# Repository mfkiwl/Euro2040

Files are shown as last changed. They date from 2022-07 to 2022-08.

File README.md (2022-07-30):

# Euro2040
 
### An RP2040 based development board designed for use in Eurorack modules

The key aims of this project are to create a board which can be used to create a Eurorack module (or standalone synthesiser) with no need for extra buffering or active circuitry.  
The board will contain internal buffering, amplification, and protection, to allow the GPIO pins to be used with up to 12V signals, allowing users to connect the pins directly to jacks to interface with other Eurorack compliant modules.

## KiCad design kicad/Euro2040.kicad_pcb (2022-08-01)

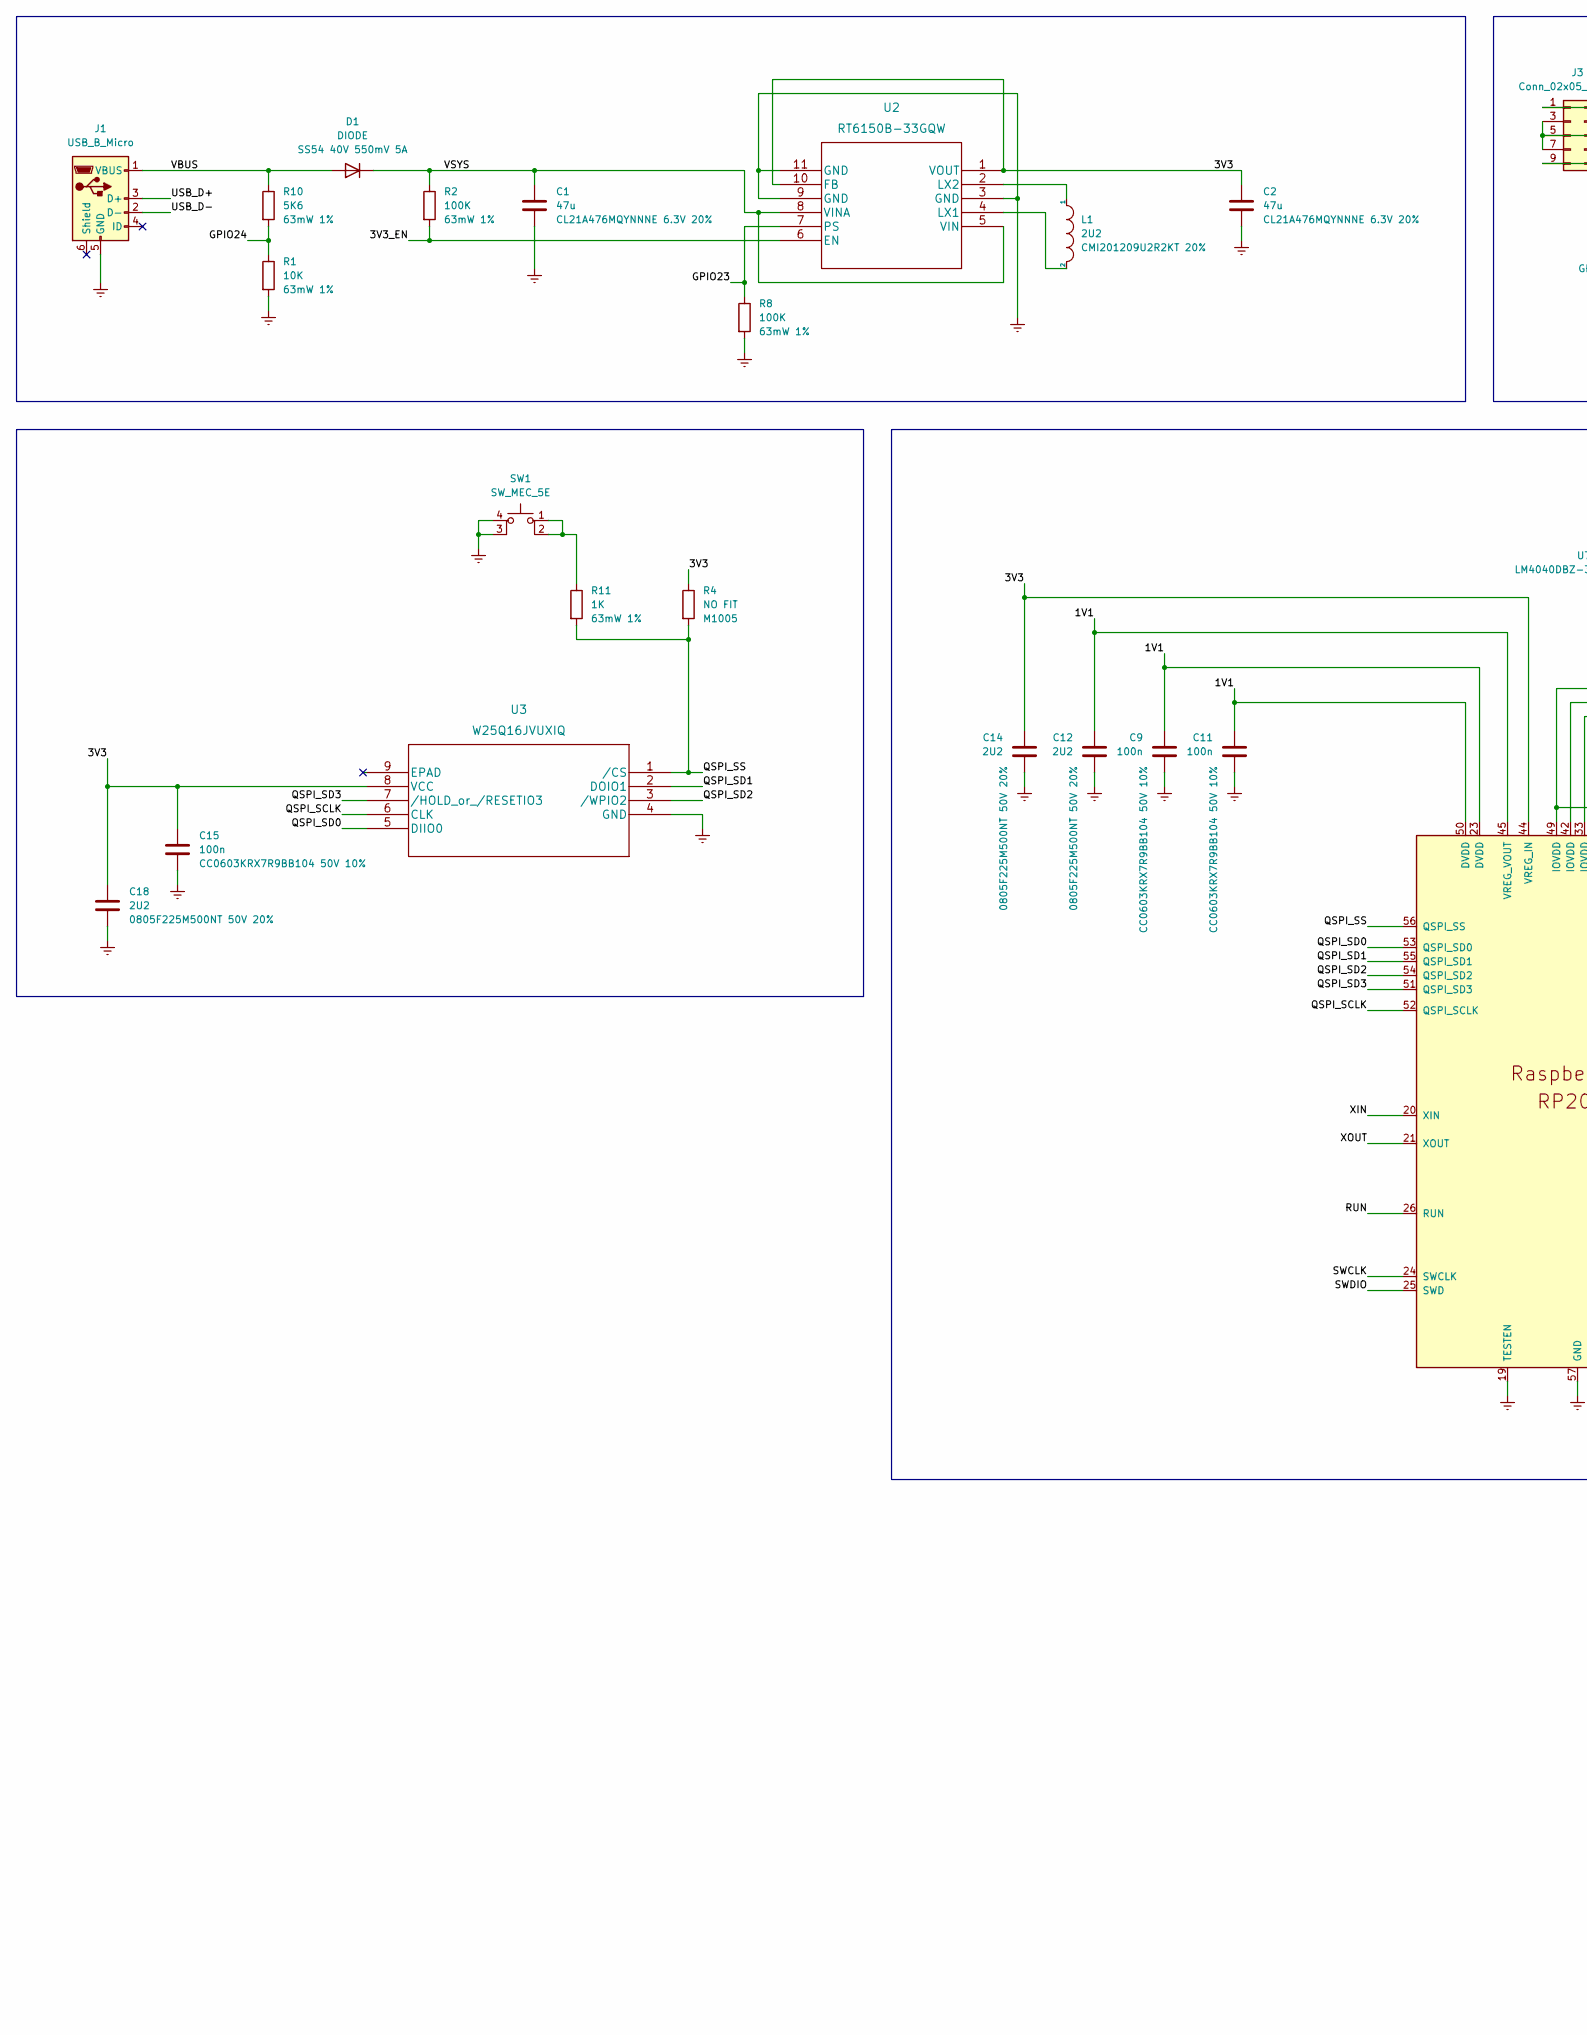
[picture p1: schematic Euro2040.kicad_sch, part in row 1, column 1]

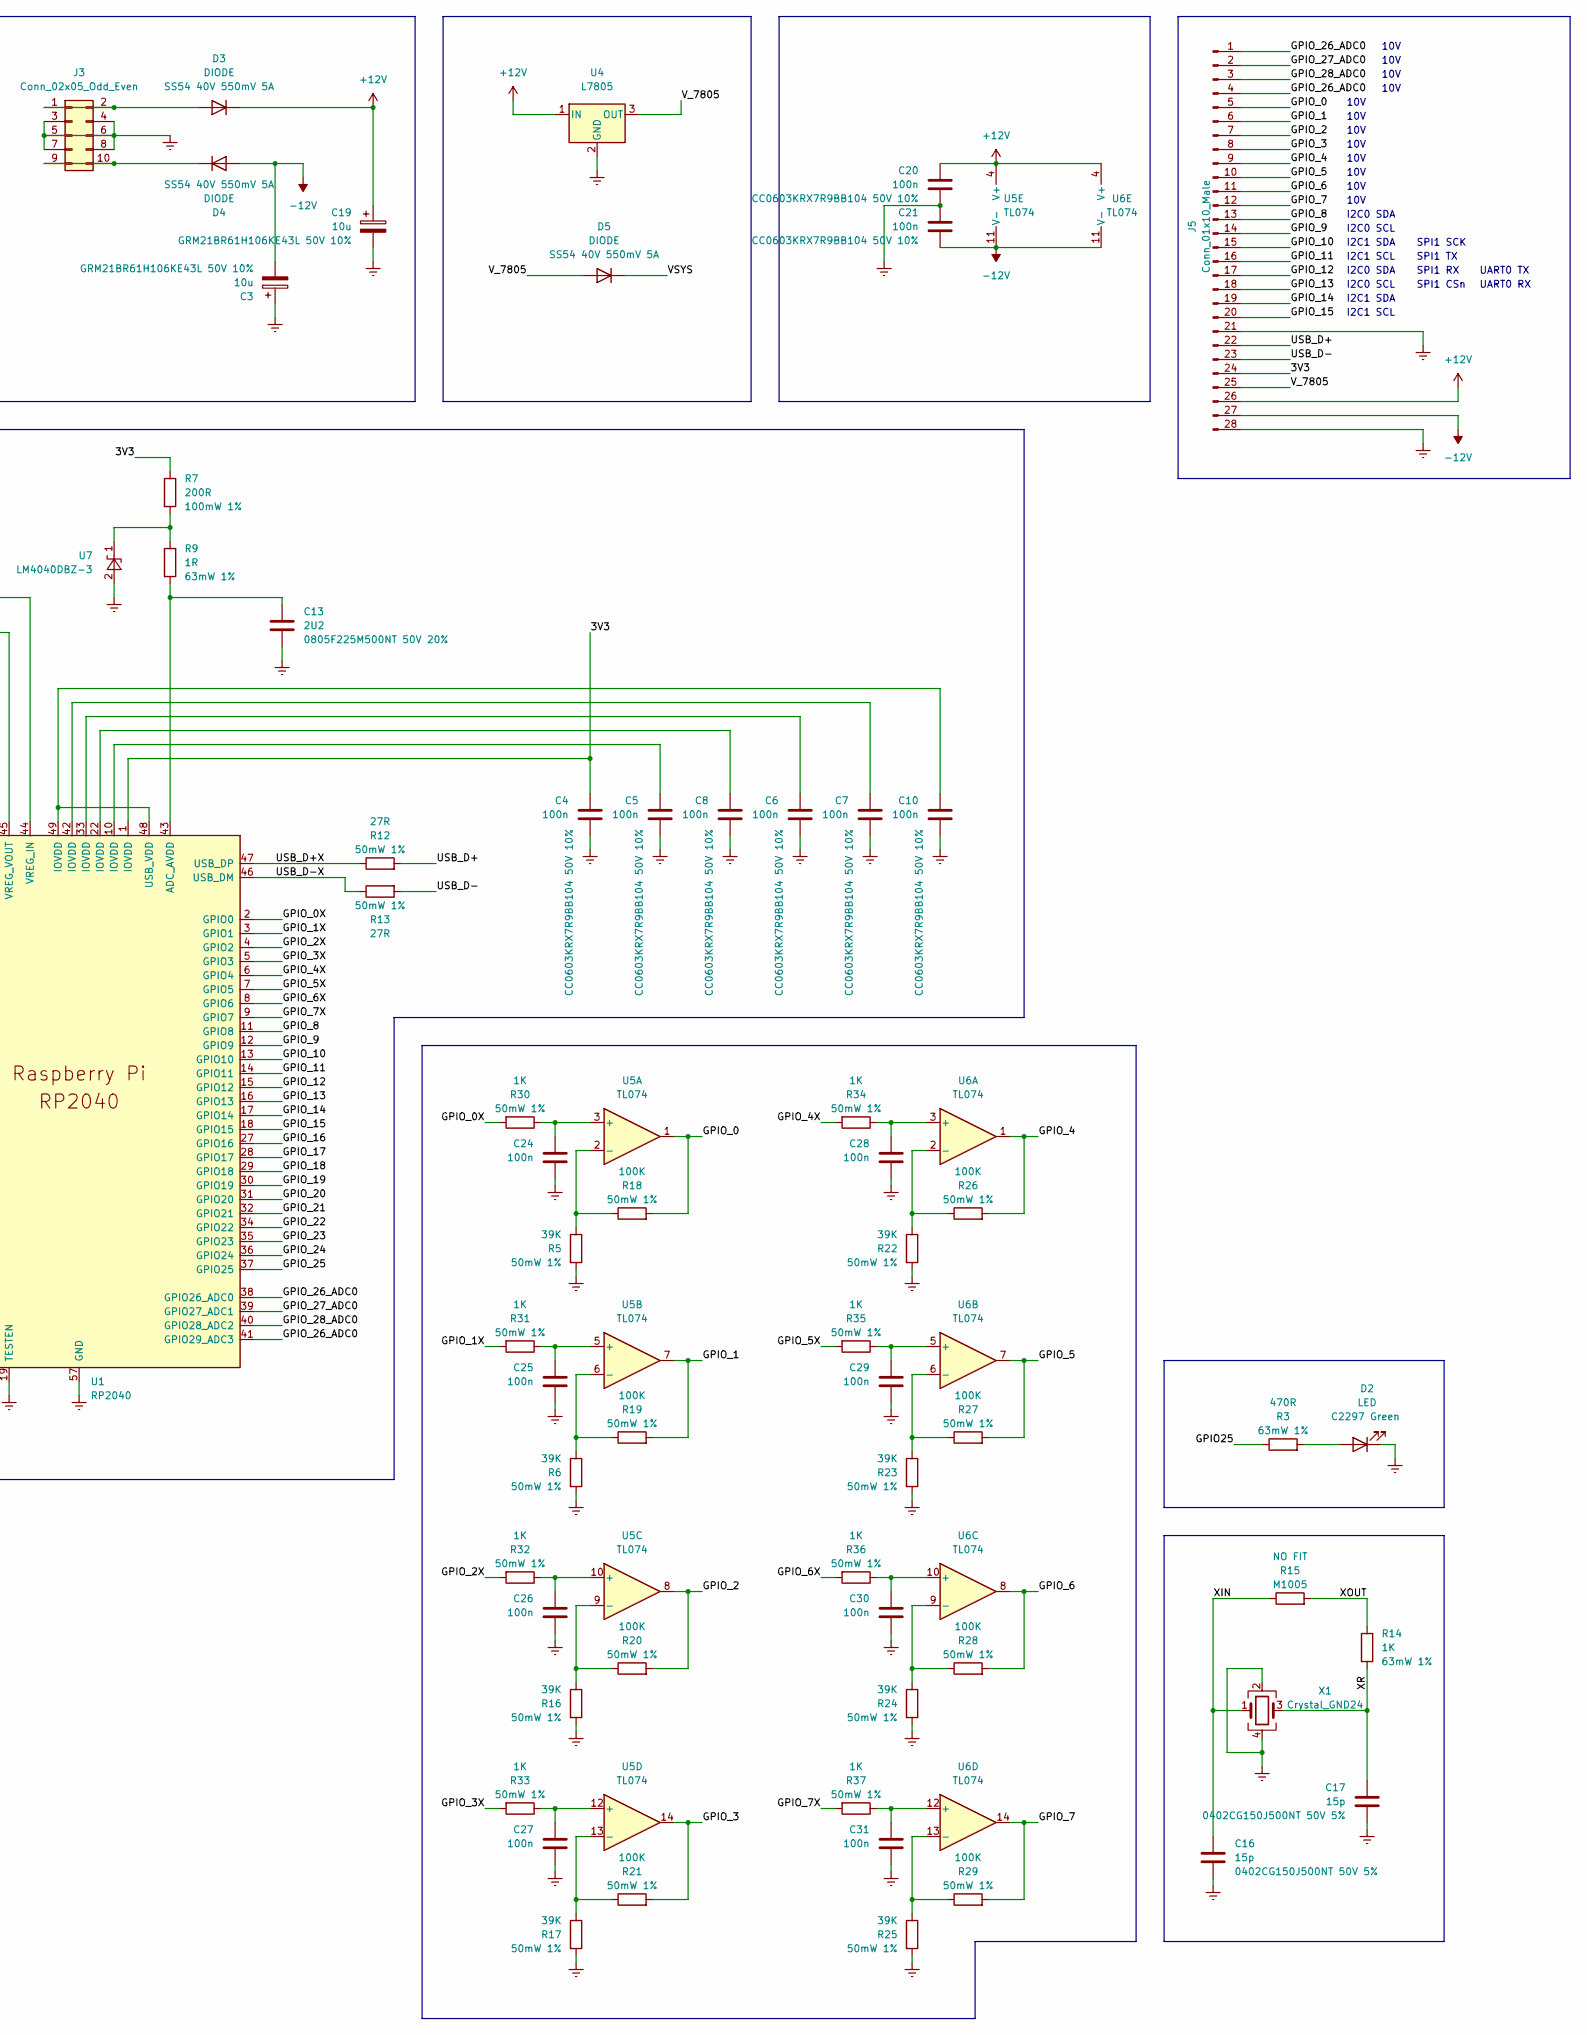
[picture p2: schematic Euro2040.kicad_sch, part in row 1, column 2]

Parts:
C1, C2: 47u; C_0402_1005Metric
C3, C19: 10u; C_0805_2012Metric
C4, C5, C6, C7, C8, C9, C10, C11, C15, C20, C21, C24, C25, C26, C27, C28, C29, C30, C31: 100n; C_0402_1005Metric
C12, C13, C14, C18: 2U2; C_0402_1005Metric
C16, C17: 15p; C_0402_1005Metric
D1, D3, D4, D5: DIODE; D_0805_2012Metric
D2: LED; LED_0402_1005Metric
J1: USB_B_Micro; USB_Micro-B_Amphenol_10103594-0001LF_Horizontal
J3: Conn_02x05_Odd_Even; Eurorack Power Header Unlabeled
J5: Conn_01x10_Male; PinHeader_1x28_P2.00mm_Horizontal
L1: 2U2; L_0402_1005Metric
R1: 10K; R_0402_1005Metric
R2, R8, R18, R19, R20, R21, R26, R27, R28, R29: 100K; R_0402_1005Metric
R3: 470R; R_0402_1005Metric
R4, R15: NO FIT; R_0402_1005Metric
R5, R6, R16, R17, R22, R23, R24, R25: 39K; R_0402_1005Metric
R7: 200R; R_0402_1005Metric
R9: 1R; R_0402_1005Metric
R10: 5K6; R_0402_1005Metric
R11, R14, R30, R31, R32, R33, R34, R35, R36, R37: 1K; R_0402_1005Metric
R12, R13: 27R; R_0402_1005Metric
SW1: SW_MEC_5E; SW_SPST_PTS810
U1: RP2040; QFN40P700X700X90-57N
U2: RT6150B-33GQW
U3: W25Q16JVUXIQ
U4: L7805; SOT-89-3
U5, U6: TL074; SOIC-14_3.9x8.7mm_P1.27mm
U7: LM4040DBZ-3; SOT-23
X1: Crystal_GND24; Crystal_SMD_3225-4Pin_3.2x2.5mm

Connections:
+12V: C19.1, C20.1, D3.2 (K), J5.26, U4.1 (IN), U5.4 (V+), U6.4 (V+)
-12V: C3.2, C21.2, D4.1 (A), J5.27, U5.11 (V-), U6.11 (V-)
/1V1: C9.1, C11.1, C12.1, U1.23 (DVDD), U1.45 (VREG_VOUT), U1.50 (DVDD)
/3V3: C2.1, C4.1, C14.1, C15.1, C18.1, J5.24, R4.1, R7.1, U1.1 (IOVDD), U1.44 (VREG_IN), U2.1 (VOUT), U2.10 (FB), U3.8 (VCC)
/3V3_EN: R2.2, U2.6 (EN)
/GPIO23: R8.1, U2.7 (PS)
/GPIO24: R1.1, R10.2
/GPIO25: R3.1
/GPIO_0: J5.5, R18.2, U5.1
/GPIO_0X: R30.2, U1.2 (GPIO0)
/GPIO_1: J5.6, R19.2, U5.7
/GPIO_1X: R31.2, U1.3 (GPIO1)
/GPIO_2: J5.7, R20.2, U5.8
/GPIO_2X: R32.2, U1.4 (GPIO2)
/GPIO_3: J5.8, R21.2, U5.14
/GPIO_3X: R33.2, U1.5 (GPIO3)
/GPIO_4: J5.9, R26.2, U6.1
/GPIO_4X: R34.2, U1.6 (GPIO4)
/GPIO_5: J5.10, R27.2, U6.7
/GPIO_5X: R35.2, U1.7 (GPIO5)
/GPIO_6: J5.11, R28.2, U6.8
/GPIO_6X: R36.2, U1.8 (GPIO6)
/GPIO_7: J5.12, R29.2, U6.14
/GPIO_7X: R37.2, U1.9 (GPIO7)
/GPIO_8: J5.13, U1.11 (GPIO8)
/GPIO_9: J5.14, U1.12 (GPIO9)
/GPIO_10: J5.15, U1.13 (GPIO10)
/GPIO_11: J5.16, U1.14 (GPIO11)
/GPIO_12: J5.17, U1.15 (GPIO12)
/GPIO_13: J5.18, U1.16 (GPIO13)
/GPIO_14: J5.19, U1.17 (GPIO14)
/GPIO_15: J5.20, U1.18 (GPIO15)
/GPIO_16: U1.27 (GPIO16)
/GPIO_17: U1.28 (GPIO17)
/GPIO_18: U1.29 (GPIO18)
/GPIO_19: U1.30 (GPIO19)
/GPIO_20: U1.31 (GPIO20)
/GPIO_21: U1.32 (GPIO21)
/GPIO_22: U1.34 (GPIO22)
/GPIO_23: U1.35 (GPIO23)
/GPIO_24: U1.36 (GPIO24)
/GPIO_25: U1.37 (GPIO25)
/GPIO_26_ADC0: J5.1, J5.4, U1.38 (GPIO26_ADC0), U1.41 (GPIO29_ADC3)
/GPIO_27_ADC0: J5.2, U1.39 (GPIO27_ADC1)
/GPIO_28_ADC0: J5.3, U1.40 (GPIO28_ADC2)
/QSPI_SCLK: U1.52 (QSPI_SCLK), U3.6 (CLK)
/QSPI_SD0: U1.53 (QSPI_SD0), U3.5 (DIIO0)
/QSPI_SD1: U1.55 (QSPI_SD1), U3.2 (DOIO1)
/QSPI_SD2: U1.54 (QSPI_SD2), U3.3 (/WPIO2)
/QSPI_SD3: U1.51 (QSPI_SD3), U3.7 (/HOLD_or_/RESETIO3)
/QSPI_SS: R4.2, R11.2, U1.56 (QSPI_SS), U3.1 (/CS)
/RUN: U1.26 (RUN)
/SWCLK: U1.24 (SWCLK)
/SWDIO: U1.25 (SWD)
/USB_D+: J1.3 (D+), J5.22, R12.2
/USB_D+X: R12.1, U1.47 (USB_DP)
/USB_D-: J1.2 (D-), J5.23, R13.2
/USB_D-X: R13.1, U1.46 (USB_DM)
/VBUS: D1.1 (A), J1.1 (VBUS), R10.1
/VSYS: C1.1, D1.2 (K), D5.2 (K), R2.1, U2.5 (VIN), U2.8 (VINA)
/V_7805: D5.1 (A), J5.25, U4.3 (OUT)
/XIN: C16.1, R15.1, U1.20 (XIN), X1.1
/XOUT: R14.1, R15.2, U1.21 (XOUT)
/XR: C17.1, R14.2, X1.3
Earth: C1.2, C2.2, C3.1, C4.2, C5.2, C6.2, C7.2, C8.2, C9.2, C10.2, C11.2, C12.2, C13.2, C14.2, C15.2, C16.2, C17.2, C18.2, C19.2, C20.2, C21.1, C24.2, C25.2, C26.2, C27.2, C28.2, C29.2, C30.2, C31.2, D2.1 (K), J1.5 (GND), J3.3, J3.4, J3.5, J3.6, J3.7, J3.8, J5.21, J5.28, R1.2, R5.2, R6.2, R8.2, R16.2, R17.2, R22.2, R23.2, R24.2, R25.2, SW1.3 (K), SW1.4 (A), U1.19 (TESTEN), U1.57 (GND), U2.3 (GND), U2.9 (GND), U2.11 (GND), U3.4 (GND), U4.2 (GND), U7.2 (A), X1.2, X1.4
unnamed: C5.1, U1.10 (IOVDD)
unnamed: C6.1, U1.33 (IOVDD)
unnamed: C7.1, U1.42 (IOVDD)
unnamed: C8.1, U1.22 (IOVDD)
unnamed: C10.1, U1.48 (USB_VDD), U1.49 (IOVDD)
unnamed: C13.1, R9.2, U1.43 (ADC_AVDD)
unnamed: D2.2 (A), R3.2
unnamed: D3.1 (A), J3.1, J3.2
unnamed: D4.2 (K), J3.9, J3.10
unnamed: L1.1, U2.2 (LX2)
unnamed: L1.2, U2.4 (LX1)
unnamed: R7.2, R9.1, U7.1 (K)
unnamed: R11.1, SW1.1, SW1.2
unnamed: R16.1, R20.1, U5.9 (-)
unnamed: R17.1, R21.1, U5.13 (-)
unnamed: R5.1, R18.1, U5.2 (-)
unnamed: R6.1, R19.1, U5.6 (-)
unnamed: R22.1, R26.1, U6.2 (-)
unnamed: R23.1, R27.1, U6.6 (-)
unnamed: R24.1, R28.1, U6.9 (-)
unnamed: R25.1, R29.1, U6.13 (-)
unnamed: C24.1, R30.1, U5.3 (+)
unnamed: C25.1, R31.1, U5.5 (+)
unnamed: C26.1, R32.1, U5.10 (+)
unnamed: C27.1, R33.1, U5.12 (+)
unnamed: C28.1, R34.1, U6.3 (+)
unnamed: C29.1, R35.1, U6.5 (+)
unnamed: C30.1, R36.1, U6.10 (+)
unnamed: C31.1, R37.1, U6.12 (+)

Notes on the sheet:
10V
SPI1 RX
I2C0 SDA
I2C1 SDA
I2C1 SCL
UART0 RX
SPI1 TX
SPI1 CSn
UART0 TX
I2C0 SCL
SPI1 SCK

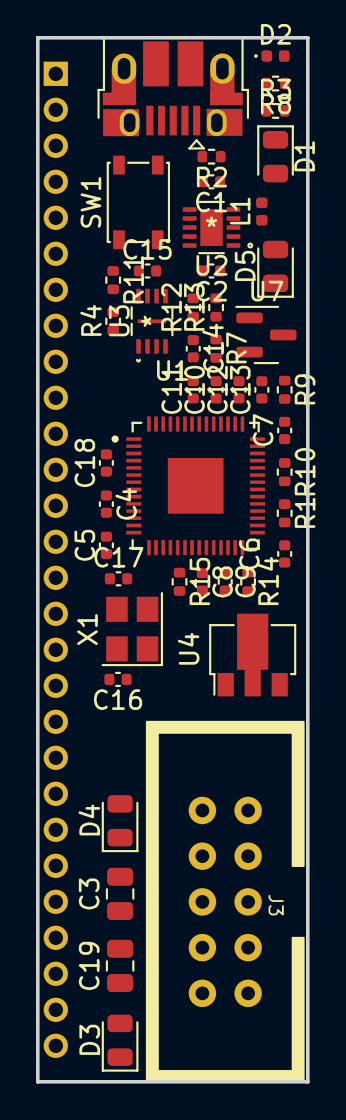
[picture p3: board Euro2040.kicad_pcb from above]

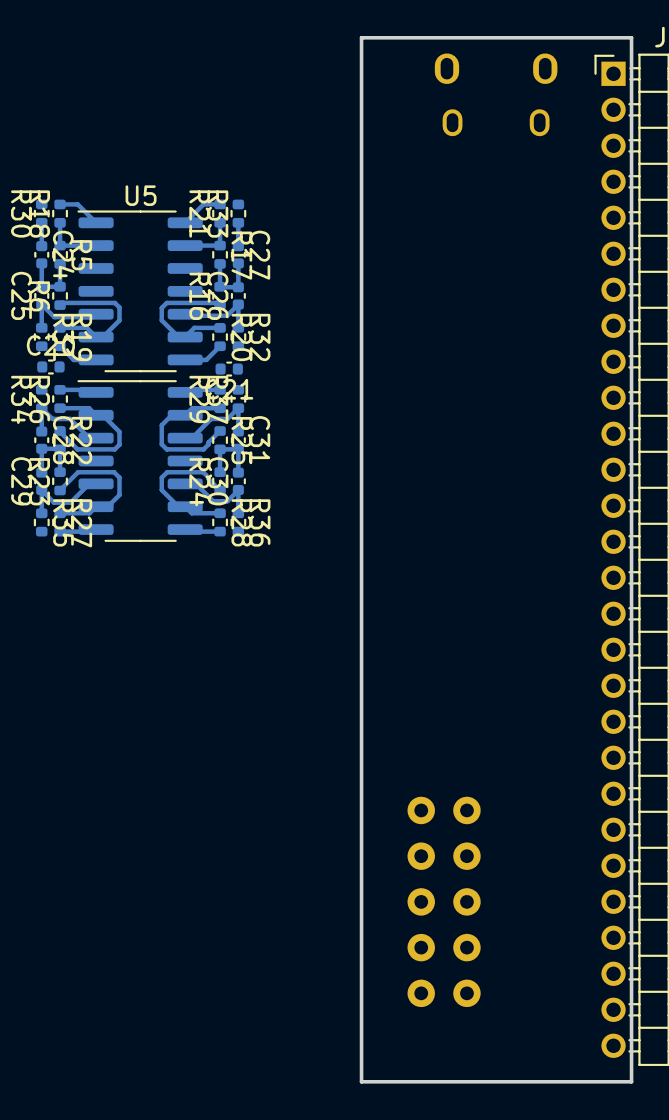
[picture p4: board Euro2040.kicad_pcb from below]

Board: 2 copper layers, 15.0 x 58.0 mm, 84 parts (37 on the bottom side), 80 nets.

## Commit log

2022-07-30 create kicad folder
    [Euro2040.kicad_pcb, Euro2040.kicad_sch]
2022-08-01 more pins, output RC filter, pcb layout
    [Euro2040.kicad_pcb, Euro2040.kicad_sch]

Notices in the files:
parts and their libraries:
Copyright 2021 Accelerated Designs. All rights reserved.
